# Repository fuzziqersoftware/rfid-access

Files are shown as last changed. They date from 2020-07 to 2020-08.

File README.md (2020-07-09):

# rfid-access

This project contains the code and schematics for a DIY device that uses a standard RFID reader to control a door lock.

This project uses:
- An Arduino Uno (you can likely use other Arduinos with the same form factor)
- A generic servo
- An HID iClass R40 RFID reader (you can buy these new or used on eBay; many office buildings use them)
- A 3D-printed cover for a deadbolt knob, to lock and unlock the door
- A custom PCB to power the servo and route the reader connections appropriately (but you don't need this - you can also use perfboard or wire manually)
- A couple of resistors, a MOSFET, and an IR LED and IR phototransistor (see schematic)

## Hardware setup

Here's what my setup looks like:

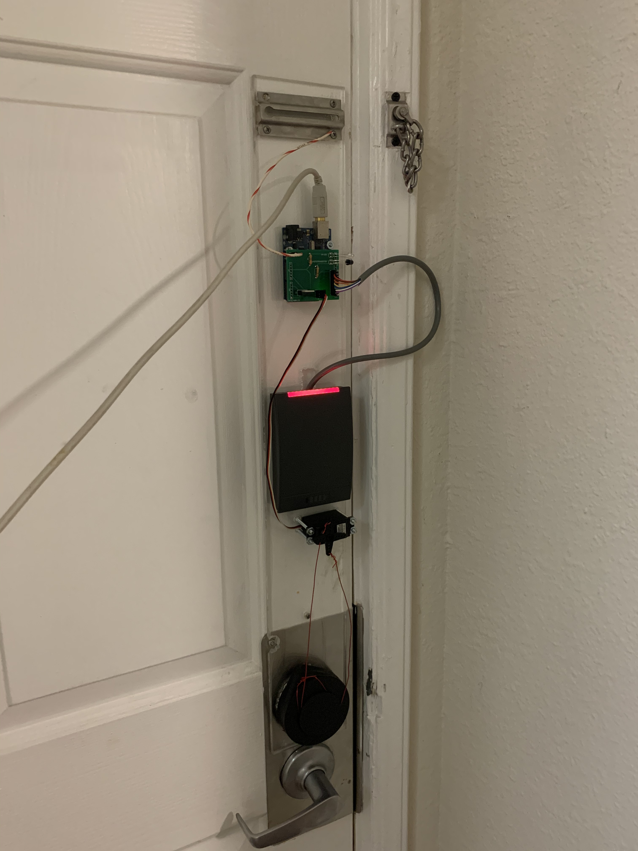
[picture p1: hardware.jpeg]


This is all on the inside of the door - from the outside, there's no indication at all that there's an RFID reader and a tiny computer attached to the door. The R40's read range is long enough that it can read cards through the door, even up to an inch or two away from the outside of the door. You just have to remember approximately where it is on the inside when you tap your card on the outside.

The hardware is all attached to a sheet of acrylic since I live in an apartment and don't want to screw things directly into the door. The acrylic is anchored under some metal door hardware, which also provides a convenient capacitive touch surface - just touch the chain deadbolt receptacle at the top to unlock the door from the inside. (You can hook this up to anything metal by soldering a wire to the EXIT-SENSE pad on the Arduino shield.)

The Arduino is attached to the acrylic with a couple of machine screws, and has a custom shield that implements this schematic:

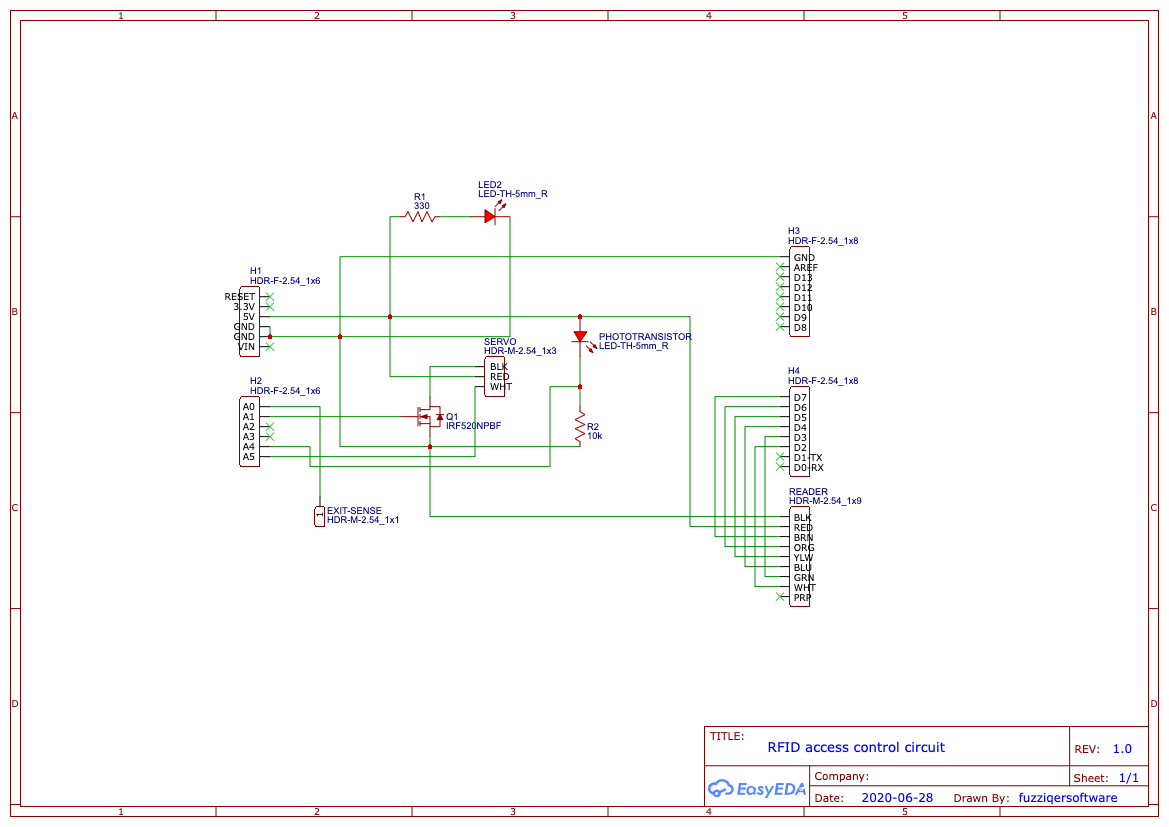
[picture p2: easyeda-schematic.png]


[Here is the EasyEDA project for the shield](https://easyeda.com/fuzziqersoftware/rfid-access-panel); the exported schematic and PCB files are also included in this repository. I ordered the PCBs through [JLCPCB](https://jlcpcb.com/) (you can do this directly from EasyEDA). The minimum order size is 5 boards, but I really only needed one, so I'll mail you a blank (unassembled) board for free if you tell me where to mail it to. (Offer expires if/when all four are mailed out.)

This board has an IR LED and a phototransistor which the software uses to detect when the door is physically closed. (These should be soldered with plenty of extra wire, so they can be bent toward the doorjamb as you see in the photo above.) When the door is unlocked, it stays unlocked for at least three seconds and at most ten seconds - after three seconds, if the phototransistor detects the wall nearby at any point, the door will relock then instead of waiting the full ten seconds.

The servo is securely fastened to the acrylic sheet, and the wires from the actuator wrap around the crown of the deadbolt knob cover.

If you have a deadbolt like mine, the deadbolt knob cover I made might also work for you. You can open the included file with Fusion 3D, export it as an STL, slice it into gcode, and 3D print it. Not all deadbolt knobs are the same, so you may need to change the shape a little. It took me eight or so iterations to get the shape right for my deadbolt knob.

The cover has two slits on the bottom side that are used to hold it in place. I stuck some long, thin circuit boards through mine and ran electrical tape around the outside of the knob cover to hold them in, but you could also use toothpicks or popsicle sticks - anything that fits and is rigid. This anchors the cover to the knob, so the wires make it turn the knob when pulled instead of just making it fall off.

## Software setup

After wiring up the reader, open up the included Arduino sketch and upload it to your Arduino. Using the serial monitor, tap your RFID cards to the reader and note the card IDs and bit counts printed in the serial monitor. (After powering it on, ignore the first card that the reader reads - the first serial number read after power-on is often wrong.)

When you've written down the card IDs that you want the unlocker to respond to, go to the TODO section in the code and put them in there. Recompile the sketch, upload it, and verify that the R40 LED turns green for several seconds after you read your predefined cards - this means they will successfully unlock your door once all the hardware is set up.

Happy hacking! Feel free to post any bugs, comments, or feature requests as GitHub issues on this repository.

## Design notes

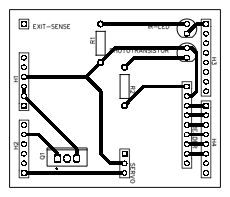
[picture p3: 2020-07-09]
easyeda-pcb.png

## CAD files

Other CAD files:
deadbolt-knob-cover.f3d

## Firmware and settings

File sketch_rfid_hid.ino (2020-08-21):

#include "pins_arduino.h"
#include <SPI.h>
#include <Servo.h>



////////////////////////////////////////////////////////////////////////////////
// pin change interrupt handlers

// All I/O pins on the Atmega168 are covered by pin change interrupts. The PCINT
// corresponding to the pin must be enabled and masked and an ISR routine
// provided. Since PCINTs are per port, not per pin, the ISR must use some logic
// to actually implement a per-pin interrupt service.

// Pin to interrupt map:
// D0-D7 = PCINT 16-23 = PCIR2 = PD = PCIE2 = pcmsk2
// D8-D13 = PCINT 0-5 = PCIR0 = PB = PCIE0 = pcmsk0
// A0-A5 (D14-D19) = PCINT 8-13 = PCIR1 = PC = PCIE1 = pcmsk1

volatile uint8_t *port_to_pcmask[] = {
  &PCMSK0,
  &PCMSK1,
  &PCMSK2,
};

static int pin_interrupt_mode[24];

typedef void (*interrupt_fn_t)(void);

volatile static interrupt_fn_t pin_interrupt_functions[24] = { 
    NULL, NULL, NULL, NULL, NULL, NULL, NULL, NULL,
    NULL, NULL, NULL, NULL, NULL, NULL, NULL, NULL,
    NULL, NULL, NULL, NULL, NULL, NULL, NULL, NULL};

volatile static uint8_t pin_register_last_state[3];

 void enable_pin_interrupt(uint8_t pin, void (*cb)(void), int mode) {
  uint8_t bit = digitalPinToBitMask(pin);
  uint8_t port = digitalPinToPort(pin);
  uint8_t slot;
  volatile uint8_t *pcmask;

  // map pin to PCIR register
  if (port == NOT_A_PORT) {
    return;
  } else {
    port -= 2;
    pcmask = port_to_pcmask[port];
  }

  if (port == 1) {
     slot = port * 8 + (pin - 14);
  } else {
     slot = port * 8 + (pin % 8);
  }

  pin_interrupt_mode[slot] = mode;
  pin_interrupt_functions[slot] = cb;
  // set the mask
  *pcmask |= bit;
  // enable the interrupt for this port
  PCICR |= 0x01 << port;
}

void disable_pin_interrupt(uint8_t pin) {
  uint8_t bit = digitalPinToBitMask(pin);
  uint8_t port = digitalPinToPort(pin);
  volatile uint8_t *pcmask;

  // map pin to PCIR register
  if (port == NOT_A_PORT) {
    return;
  } 
  else {
    port -= 2;
    pcmask = port_to_pcmask[port];
  }

  *pcmask &= ~bit;

  // disable the port interrupt if there are no pin interrupts remaining
  if (*pcmask == 0) {
    PCICR &= ~(0x01 << port);
  }
}

static void port_interrupt_handler(uint8_t port) {
  // get the pin states for the indicated port.
  uint8_t curr = *portInputRegister(port + 2);
  uint8_t mask = curr ^ pin_register_last_state[port];
  pin_register_last_state[port] = curr;

  // mask is the pins that have changed; filter out those that don't have
  // registered handlers
  mask &= *port_to_pcmask[port];
  if (mask == 0) {
    return;
  }

  for (uint8_t x = 0; x < 8; x++) {
    uint8_t bit = 0x01 << x;
    if (!(bit & mask)) {
      continue;
    }

    uint8_t pin = port * 8 + x;
    if (pin_interrupt_functions[pin] == NULL) {
      continue;
    }

    if ((pin_interrupt_mode[pin] == CHANGE) ||
        ((pin_interrupt_mode[pin] == RISING) && (curr & bit)) ||
        ((pin_interrupt_mode[pin] == FALLING) && !(curr & bit))) {
      pin_interrupt_functions[pin]();
    }
  }
}

SIGNAL(PCINT0_vect) {
  port_interrupt_handler(0);
}
SIGNAL(PCINT1_vect) {
  port_interrupt_handler(1);
}
SIGNAL(PCINT2_vect) {
  port_interrupt_handler(2);
}



////////////////////////////////////////////////////////////////////////////////
// wiegand protocol decoder

volatile uint8_t wiegand_count;
volatile uint8_t wiegand_data[16];
volatile uint32_t wiegand_last_recv_time;

void on_wiegand_bit(uint8_t bit) {
  if (bit) {
    wiegand_data[wiegand_count >> 3] |= (1 << (7 - (wiegand_count & 7)));
  }
  wiegand_count++;
  wiegand_last_recv_time = millis();
}

void on_wiegand_zero() {
  on_wiegand_bit(0);
}

void on_wiegand_one() {
  on_wiegand_bit(1);
}

void clear_wiegand_value() {
  wiegand_count = 0;
  for (uint8_t x = 0; x < 16; x++) {
    wiegand_data[x] = 0;
  }
  wiegand_last_recv_time = millis();
}

void enable_wiegand_reader(int data0_pin, int data1_pin) {
  clear_wiegand_value();
  pinMode(data0_pin, INPUT);
  pinMode(data1_pin, INPUT);
  enable_pin_interrupt(data0_pin, on_wiegand_zero, FALLING);
  enable_pin_interrupt(data1_pin, on_wiegand_one, FALLING);
}



////////////////////////////////////////////////////////////////////////////////

uint8_t read_capacitive_pin(int pin_num) {
  volatile uint8_t* port = portOutputRegister(digitalPinToPort(pin_num));
  volatile uint8_t* ddr = portModeRegister(digitalPinToPort(pin_num));
  byte bitmask = digitalPinToBitMask(pin_num);
  volatile uint8_t* pin = portInputRegister(digitalPinToPort(pin_num));

  // Discharge the pin first by setting it low and output
  *port &= ~(bitmask);
  *ddr  |= bitmask;
  delay(1);

  // Prevent the timer IRQ from disturbing our measurement
  uint8_t SREG_old = SREG; //back up the AVR Status Register
  noInterrupts();

  // Make the pin an input with the internal pull-up on
  *ddr &= ~(bitmask);
  *port |= bitmask;

  // Now see how long the pin to get pulled up. This manual unrolling of the loop
  // decreases the number of hardware cycles between each read of the pin,
  // thus increasing sensitivity.
  uint8_t cycles = 17;
  if (*pin & bitmask) { cycles =  0;}
  else if (*pin & bitmask) { cycles =  1;}
  else if (*pin & bitmask) { cycles =  2;}
  else if (*pin & bitmask) { cycles =  3;}
  else if (*pin & bitmask) { cycles =  4;}
  else if (*pin & bitmask) { cycles =  5;}
  else if (*pin & bitmask) { cycles =  6;}
  else if (*pin & bitmask) { cycles =  7;}
  else if (*pin & bitmask) { cycles =  8;}
  else if (*pin & bitmask) { cycles =  9;}
  else if (*pin & bitmask) { cycles = 10;}
  else if (*pin & bitmask) { cycles = 11;}
  else if (*pin & bitmask) { cycles = 12;}
  else if (*pin & bitmask) { cycles = 13;}
  else if (*pin & bitmask) { cycles = 14;}
  else if (*pin & bitmask) { cycles = 15;}
  else if (*pin & bitmask) { cycles = 16;}

  // End of timing-critical section; turn interrupts back on if they were on before, or leave them off if they were off before
  SREG = SREG_old;

  // Discharge the pin again by setting it low and output
  //  It's important to leave the pins low if you want to 
  //  be able to touch more than 1 sensor at a time - if
  //  the sensor is left pulled high, when you touch
  //  two sensors, your body will transfer the charge between
  //  sensors.
  *port &= ~(bitmask);
  *ddr  |= bitmask;

  return cycles;
}



////////////////////////////////////////////////////////////////////////////////
// main program

// pin assignments
int reader_data0_pin = 3; // green from R40
int reader_data1_pin = 2; // white from R40
int servo_control_pin = A5; // white wire from servo
int relay_control_pin = A1;
int reader_hold_pin = 4; // blue from R40
int reader_beeper_pin = 5; // yellow from R40
int reader_green_led_pin = 6; // orange from R40
int reader_red_led_pin = 7; // brown from R40
int exit_sense_pin = A0; // exit switch
int ir_phototransistor_sense_pin = A4;

Servo servo;

void setup() {
  enable_wiegand_reader(reader_data0_pin, reader_data1_pin);
  pinMode(relay_control_pin, OUTPUT);
  pinMode(reader_hold_pin, OUTPUT);
  pinMode(reader_beeper_pin, OUTPUT);
  pinMode(reader_green_led_pin, OUTPUT);
  pinMode(reader_red_led_pin, OUTPUT);
  pinMode(ir_phototransistor_sense_pin, INPUT);
  delay(100);

  Serial.begin(115200);
  Serial.println("inited");

  digitalWrite(reader_hold_pin, HIGH); // disable HOLD
  digitalWrite(reader_beeper_pin, HIGH); // disable BEEPER
  digitalWrite(reader_green_led_pin, HIGH); // disable GREEN LED
  digitalWrite(reader_red_led_pin, HIGH); // disable RED LED

  servo.attach(servo_control_pin);

  actuate_servo_temporary(0);
}

void actuate_servo_temporary(int position) {
  servo.write(position);

  digitalWrite(relay_control_pin, HIGH); // activate relay (activating servo)
  delay(1500); // wait for servo to get to position
  digitalWrite(relay_control_pin, LOW); // deactivate relay + servo
}

bool is_open() {
  return digitalRead(ir_phototransistor_sense_pin) == LOW;
}

void unlock() {
  digitalWrite(reader_hold_pin, LOW); // enable HOLD
  digitalWrite(reader_green_led_pin, LOW); // set reader LED to green

  actuate_servo_temporary(180);
  long open_time = millis();
  delay(3000);
  long is_open_time = millis();
  while ((millis() - open_time < 10000) && (millis() - is_open_time < 1000)) {
    if (is_open()) {
      is_open_time = millis();
    }
    delay(100);
  }
  actuate_servo_temporary(0);

  digitalWrite(reader_green_led_pin, HIGH); // set reader LED to red
  digitalWrite(reader_hold_pin, HIGH); // disable HOLD
}

bool memcmp_bits(const uint8_t* a, const uint8_t* b, size_t bits) {
  while (bits >= 8) {
    if (*a != *b) {
      return true;
    }
    a++;
    b++;
    bits -= 8;
  }

  uint8_t mask_for_bit_count[8] = {
    0x00, 0x80, 0xC0, 0xE0, 0xF0, 0xF8, 0xFC, 0xFE,
  };
  if (bits != 0) {
    uint8_t mask = mask_for_bit_count[bits];
    if ((*a & mask) != (*b & mask)) {
      return true;
    }
  }

  return false;
}

void on_card_read(const uint8_t* data, uint16_t bit_count) {
  Serial.print("on_card_read: bits=");
  Serial.print(bit_count);
  Serial.print(" data=0x");
  uint8_t bytes_to_print = bit_count >> 3;
  if ((bytes_to_print << 3) != bit_count) {
    bytes_to_print++;
  }
  for (uint16_t offset = 0; offset < bytes_to_print; offset++) {
    // Serial.print(..., HEX) doesn't print leading zeroes
    if ((data[offset] & 0xF0) == 0x00) {
      Serial.print("0");
    }
    Serial.print(data[offset], HEX);
  }
  Serial.println();

  // TODO: Add your cards here! Set num_accepted appropriately, then remove the
  // examples and put your own card's ID. To find your card's ID, wire up the
  // reader and power the Arduino from your computer's USB port. The Arduino
  // will print the card's ID to the serial monitor each time the reader reads
  // a card. But watch out: after power-on, sometimes the first card read by
  // the reader is sent incorrectly. To make sure you have the right ID, read
  // it twice.
  const uint8_t num_accepted = 2;
  const uint8_t expected_data[num_accepted][16] = {
    // 35-bit example
    {0xA5, 0x39, 0x58, 0x03, 0x20, 0x00, 0x00, 0x00, 0x00, 0x00, 0x00, 0x00, 0x00, 0x00, 0x00, 0x00},
    // 42-bit example
    {0x38, 0x77, 0x2A, 0x94, 0xF6, 0x40, 0x00, 0x00, 0x00, 0x00, 0x00, 0x00, 0x00, 0x00, 0x00, 0x00},
  };
  const uint8_t expected_bits[num_accepted] = {
    35, 42,
  };

  bool found = false;
  for (uint8_t index = 0; index < num_accepted; index++) {
    if (bit_count != expected_bits[index]) {
      continue;
    }
    if (memcmp_bits(data, expected_data[index], bit_count)) {
      continue;
    }
    found = true;
  }

  if (found) {
    // if the door is already open, warn (by beeping twice)
    if (is_open()) {
      digitalWrite(reader_beeper_pin, LOW);
      delay(100);
      digitalWrite(reader_beeper_pin, HIGH);
      delay(100);
      digitalWrite(reader_beeper_pin, LOW);
      delay(100);
      digitalWrite(reader_beeper_pin, HIGH);
    }

    unlock();
  }
}

void loop() {
  wiegand_last_recv_time = millis();
  long last_open_sense_time = wiegand_last_recv_time;

  // wait until there's data, and we haven't received any new data for 100ms
  while ((wiegand_count == 0) || (wiegand_last_recv_time > millis() - 100)) {
    if (last_open_sense_time < millis() - 500) {
      last_open_sense_time = millis();
      is_open();
    }
    if (digitalRead(exit_sense_pin) == HIGH) {
      unlock();
    }
  }

  if (wiegand_count > 0) {
    on_card_read(wiegand_data, wiegand_count);
  }

  clear_wiegand_value();
}
